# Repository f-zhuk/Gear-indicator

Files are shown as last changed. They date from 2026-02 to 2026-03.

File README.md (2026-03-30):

# Gear-indicator
A system to monitor the selected gear for bicycles, for those who do not trust their memory

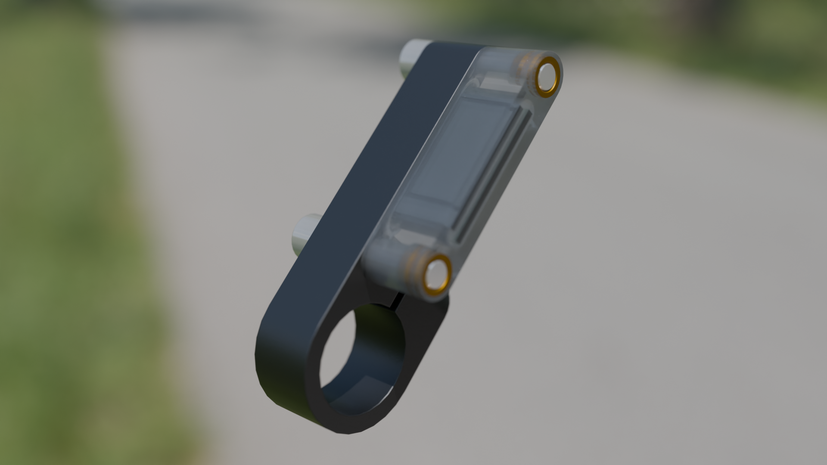
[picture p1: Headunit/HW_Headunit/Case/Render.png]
description


Headunit - a device to display the current gear
Gearunit - a device to transmit the current position of two cables, doubles as a power supply

### System manifest

The main idea of the system is to minimize interaction with the user, reduce buttons and/or settings to the minimum.

The system is designed for long-term/permanent installation and should require minimal maintenance. All its modules should be waterproof and vandal-resistant.

System retains its settings in the local RAM of the corresponding units, always powered from the Battery/shifter unit. If that battery goes flat, all system parameters are lost, and calibration (or learning) should be performed after turning on. Modules can be disconnected from power independently, so it will affect only the related module parameters. 

### Calibration

Whatever position the shifter was left in, it will be considered a first gear after the cold start. First shift has to be upwards, even an incomplete one, to point the cable’s forward direction. If the Headunit reads values outside of the known range, the current gear indicator will move away, and if the value stays stable for ~2 seconds, the gear count and associated shifter value table will be updated.

To save battery, all modules should go in and out of deep sleep upon Headunit's request. While active, deep sleep should be triggered if no movement is detected for a minute. 
While in a deep sleep, any movement should trigger a deep sleep exit.

With an IMU within the battery module firmly attached to the bicycle frame, it is possible to estimate bike speed.

Braking range can be determined and dynamically expanded on the fly.

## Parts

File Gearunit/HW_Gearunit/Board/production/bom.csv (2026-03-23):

Designator | Footprint | Quantity | Value | LCSC Part #
C1, C4, C6, C73 | 0603 | 4 | 1u | CL10A105KB8NNNC
C2, C3, C5, C68, C7 | 0402 | 5 | 100n | CL05B104KB54PNC
D1 | SOT-23 | 1 | SP0502BAHT | SP0502BAHT
F1 | 0603 | 1 | 0603L020YR | 0603L020YR
J1, J2 | XB-PJ-1837 | 2 | XB-PJ-1837 | XB-PJ-1837
J3 | TE_2328702-8_1x08-1MP_P0.5mm_Horizontal | 1 | 2328702-8 | 2328702-8
J4 | HS096T01H13 | 1 | HS096T01H13 | HS096T01H13
Q2, Q3 | SOT-563 | 2 | DMC2400UV | DMC2400UV
R1, R2 | 0805 | 2 | 62R | RC0805FR-0762RL
R10, R13, R3, R4, R5, R6, R8, R9 | 0402 | 8 | 10k | 0402WGF1002TCE
R11, R12, R7 | 0402 | 3 | 10R | 0402WGF100JTCE
U1 | QFN-32-1EP_5x5mm_P0.5mm_EP3.45x3.45mm | 1 | STM32L432KBUx | STM32L432KBU
U2 | SOT-23-3 | 1 | XC6206P332MR-G | XC6206P332MR-G
U3 | DFN-8-1EP_3x3mm_P0.65mm_EP1.5x2.25mm | 1 | SIT1050TK | SIT1050TK

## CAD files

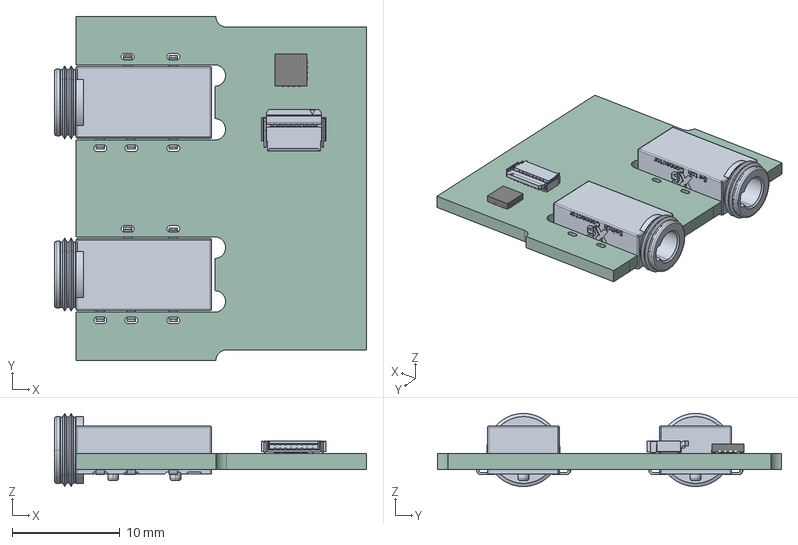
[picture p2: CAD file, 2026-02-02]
Headunit/HW_Headunit/Board/HW_Headunit.step
29.0 x 32.0 x 6.80 mm
c-2328702-8-a-3d
QFN-16-1EP_3x3mm_P0.5mm_EP1.7x1.7mm
xb-pj-1837 x 2
HW_Headunit_PCB

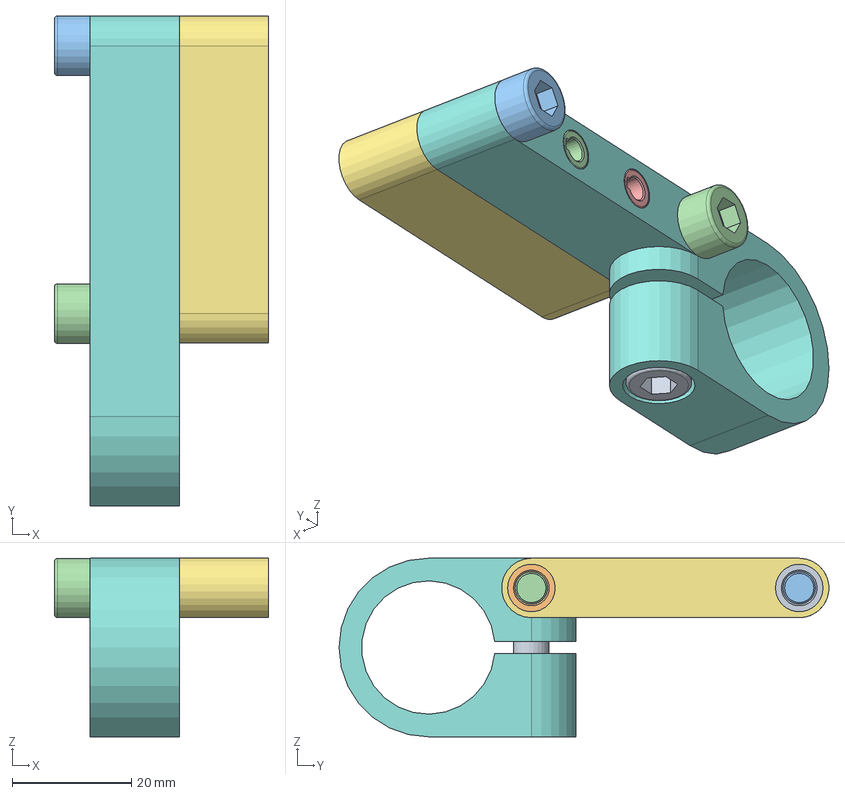
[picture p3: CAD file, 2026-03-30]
Headunit/HW_Headunit/Case/Headunit.FCStd
36.0 x 82.3 x 30.0 mm
DIN912_M6X30_001
DIN912_M6X30_002
R_0402_1005Metric
R_0805_2012Metric
R_0402_1005Metric001
C_0402_1005Metric
R_0402_1005Metric002
SOT-563
R_0402_1005Metric003
R_0402_1005Metric004
SOT-23-3
DFN-8-1EP_3x3mm_P0.65mm_EP1.5x2.25mm
Fuse_0603_1608Metric
C_0603_1608Metric
HS096T01H13
R_0402_1005Metric005
C_0402_1005Metric001
C_0402_1005Metric002
c-2328702-8-a-3d
R_0402_1005Metric006
R_0402_1005Metric007
R_0402_1005Metric008
R_0402_1005Metric009
QFN-32-1EP_5x5mm_P0.5mm_EP3.45x3.45mm
SOT-564
SOT-23
R_0402_1005Metric010
C_0603_1608Metric001
R_0805_2012Metric001
C_0402_1005Metric003
C_0603_1608Metric002
C_0603_1608Metric003
C_0402_1005Metric004
xb-pj-1837
xb-pj-1838
HW_Headunit_PCB
DIN912_M6X12_001

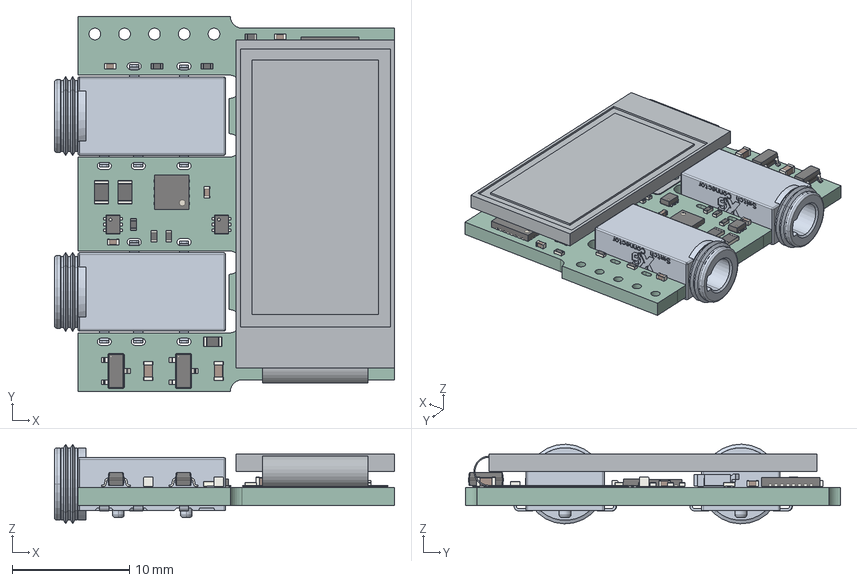
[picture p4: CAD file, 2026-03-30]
Headunit/HW_Headunit/Case/HW_Headunit.step
29.0 x 32.0 x 6.80 mm
R_0402_1005Metric x 11
R_0805_2012Metric x 2
C_0402_1005Metric x 5
SOT-563 x 2
SOT-23-3
DFN-8-1EP_3x3mm_P0.65mm_EP1.5x2.25mm
Fuse_0603_1608Metric
C_0603_1608Metric x 4
HS096T01H13
c-2328702-8-a-3d
QFN-32-1EP_5x5mm_P0.5mm_EP3.45x3.45mm
SOT-23
xb-pj-1837 x 2
HW_Headunit_PCB

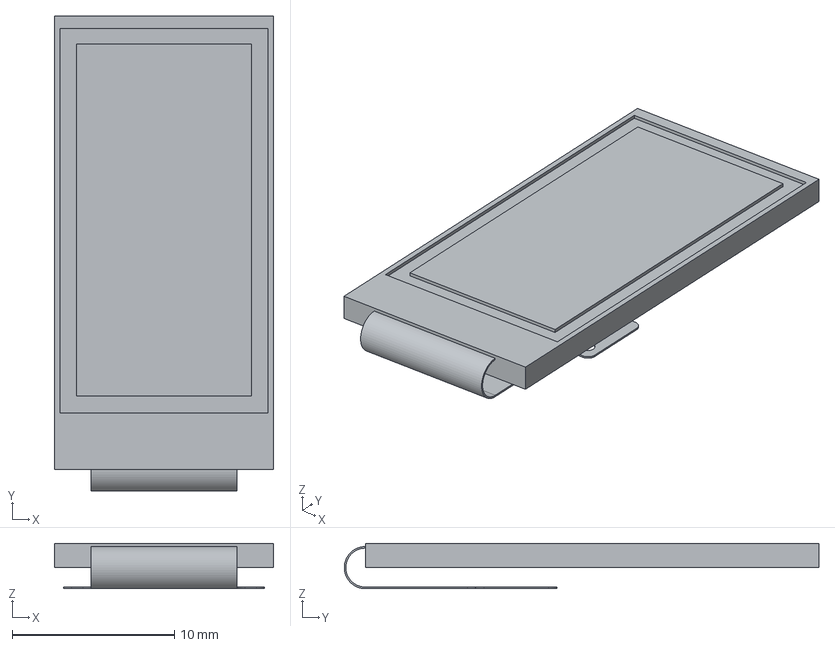
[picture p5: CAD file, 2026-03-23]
Headunit/HW_Headunit/Case/HS096T01H13.step
13.5 x 29.2 x 2.80 mm

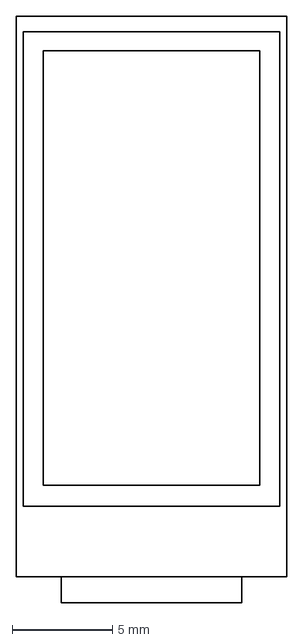
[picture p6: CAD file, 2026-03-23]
Headunit/HW_Headunit/Case/HS096T01H13-Shape2DView.dxf
13.5 x 29.2 mm

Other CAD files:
Headunit/HW_Headunit/Case/LH096NT-IF09W.step
Headunit/HW_Headunit/Case/HS096T01H13.FCStd
Headunit/HW_Headunit/Case/Headunit.blend
Headunit/HW_Headunit/Case/LH096NT-IF09W.FCStd

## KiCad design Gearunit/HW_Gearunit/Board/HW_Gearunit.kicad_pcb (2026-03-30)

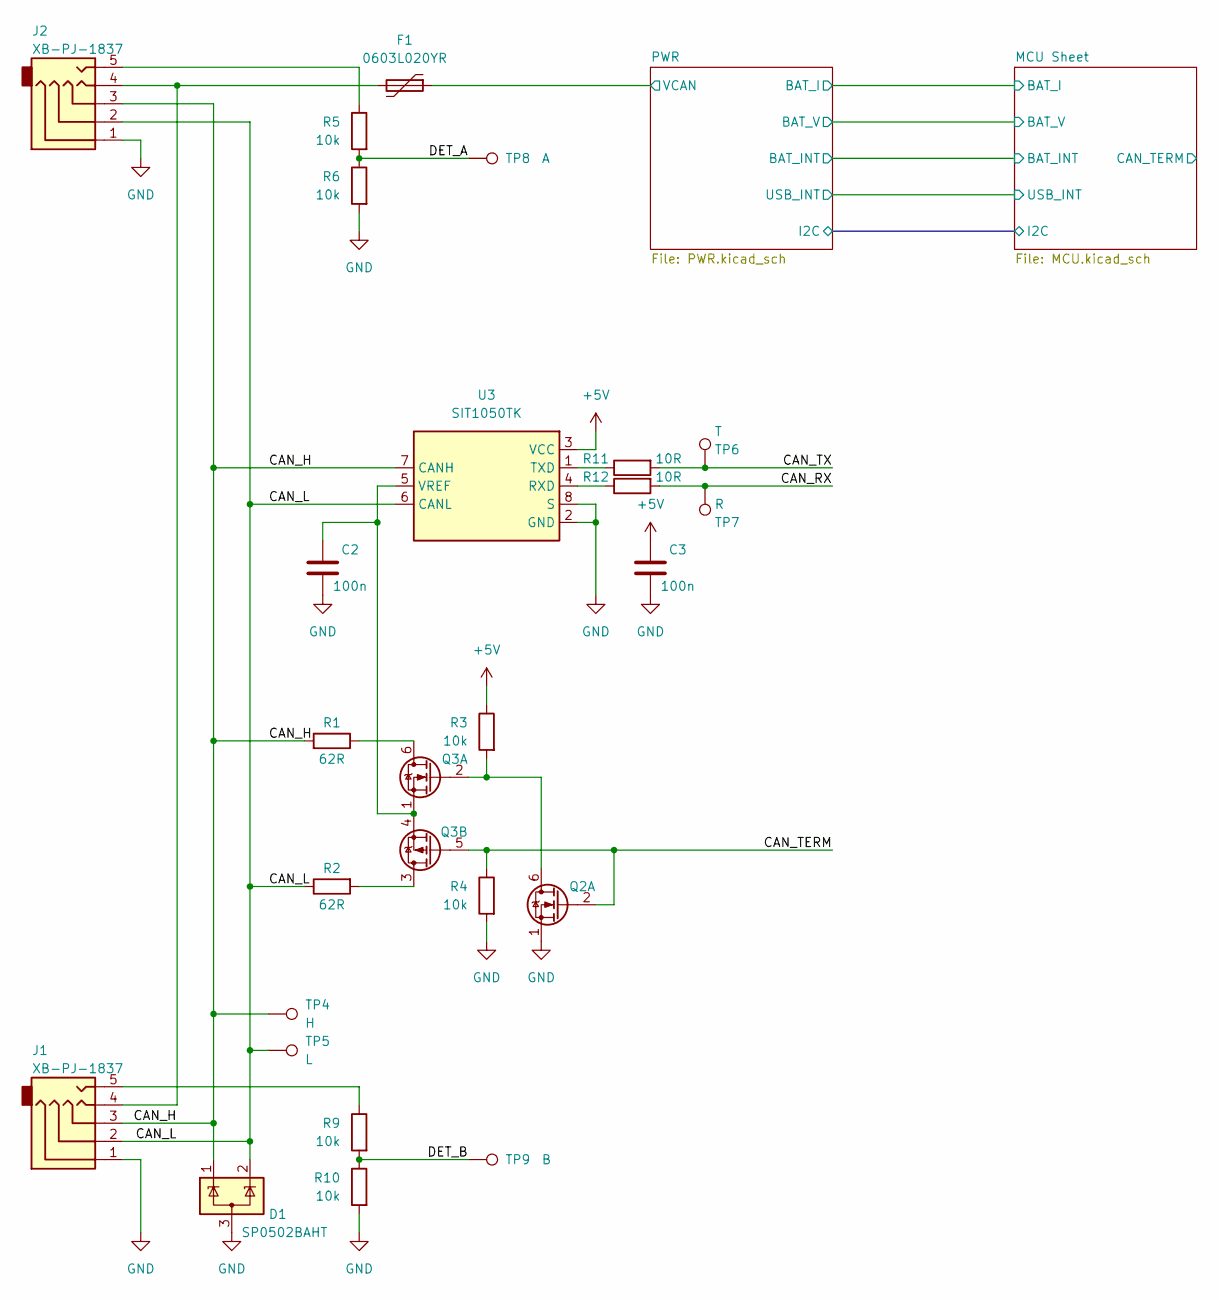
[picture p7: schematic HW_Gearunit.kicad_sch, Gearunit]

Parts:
C2, C3: 100n; C_0402_1005Metric; MPN CL05B104KB54PNC
D1: SP0502BAHT; SOT-23; MPN SP0502BAHT
F1: 0603L020YR; Fuse_0603_1608Metric; MPN 0603L020YR
J1, J2: XB-PJ-1837; MPN XB-PJ-1837
Q2, Q3: DMC2400UV; SOT-563; MPN DMC2400UV
R1, R2: 62R; R_0805_2012Metric; MPN RC0805FR-0762RL
R3, R4, R5, R6, R9, R10: 10k; R_0402_1005Metric; MPN 0402WGF1002TCE
R11, R12: 10R; R_0402_1005Metric; MPN 0402WGF100JTCE
TP4: H; TestPoint_Pad_D1.5mm
TP5: L; TestPoint_Pad_D1.5mm
TP6: T; TestPoint_Pad_D1.5mm
TP7: R; TestPoint_Pad_D1.5mm
TP8: A; TestPoint_Pad_D1.5mm
TP9: B; TestPoint_Pad_D1.5mm
U3: SIT1050TK; DFN-8-1EP_3x3mm_P0.65mm_EP1.5x2.25mm; MPN SIT1050TK

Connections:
+5V: C3.2, R3.1, U3.3 (VCC)
/CAN_H: D1.1 (K), J1.3, J2.3, R1.2, TP4.1, U3.7 (CANH)
/CAN_L: D1.2 (K), J1.2, J2.2, R2.1, TP5.1, U3.6 (CANL)
/CAN_RX: R12.2, TP7.1
/CAN_TERM: Q2.2 (G), Q3.5 (G), R4.1
/CAN_TX: R11.2, TP6.1
/DET_A: R5.2, R6.1, TP8.1
/DET_B: R9.2, R10.1, TP9.1
/PWR/VCAN: F1.1; also elsewhere on the board
GND: C2.1, C3.1, D1.3 (A), J1.1, J2.1, Q2.1 (S), R4.2, R6.2, R10.2, U3.2 (GND), U3.8 (S); also elsewhere on the board
unnamed: F1.2, J1.4, J2.4
unnamed: J1.5, R9.1
unnamed: J2.5, R5.1
unnamed: Q2.6 (D), Q3.2 (G), R3.2
unnamed: Q3.6 (D), R1.1
unnamed: C2.2, Q3.1 (S), Q3.4 (S), U3.5 (VREF)
unnamed: Q3.3 (D), R2.2
unnamed: R12.1, U3.4 (RXD)
unnamed: R11.1, U3.1 (TXD)

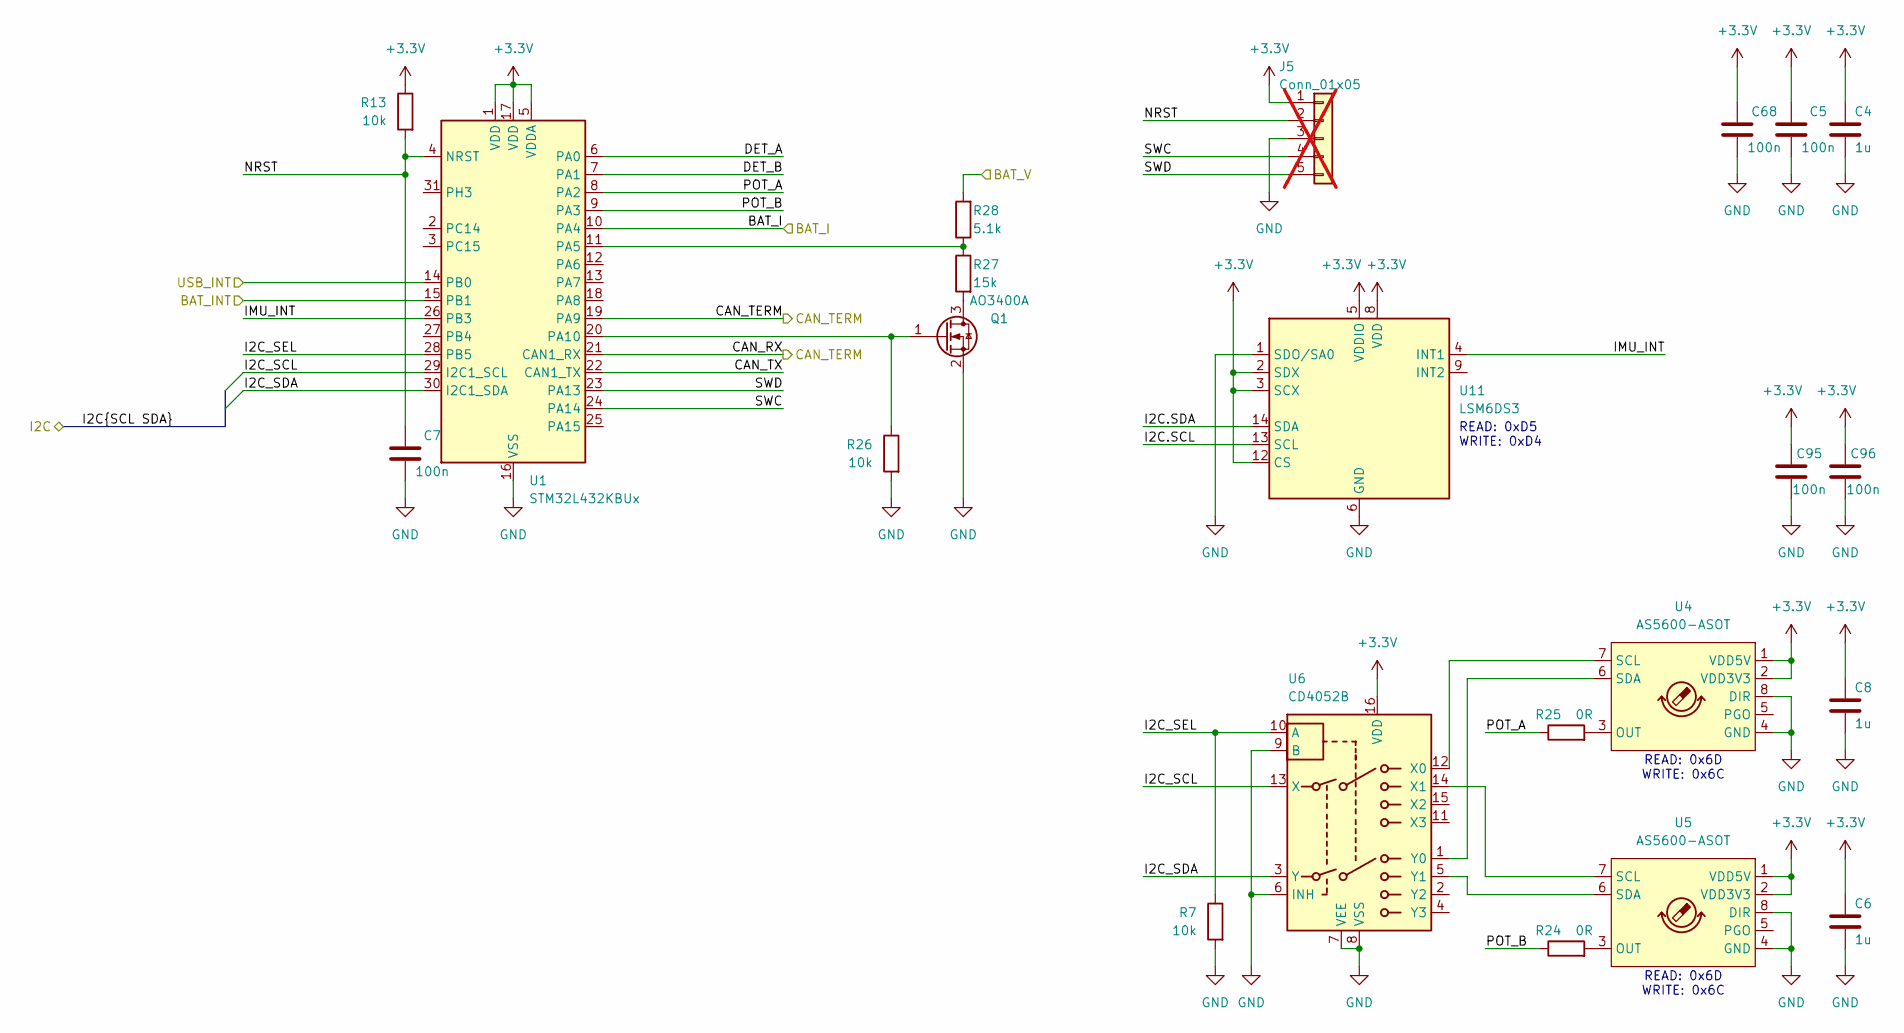
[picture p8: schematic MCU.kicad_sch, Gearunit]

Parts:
C4, C6, C8: 1u; C_0603_1608Metric; MPN CL10A105KB8NNNC
C5, C7, C68, C95, C96: 100n; C_0402_1005Metric; MPN CL05B104KB54PNC
J5: Conn_01x05; PinHeader_1x05_P2.54mm_Vertical; not fitted
Q1: AO3400A; SOT-23; MPN AO3400A
R7, R13, R26: 10k; R_0402_1005Metric; MPN 0402WGF1002TCE
R24, R25: 0R; R_0402_1005Metric; MPN 0402WGF0000TCE
R27: 15k; R_0402_1005Metric; MPN 0402WGF1502TCE
R28: 5.1k; R_0402_1005Metric; MPN 0402WGF5101TCE
U1: STM32L432KBUx; QFN-32-1EP_5x5mm_P0.5mm_EP3.45x3.45mm; MPN STM32L432KBU
U4, U5: AS5600-ASOT; SO-8_3.9x4.9mm_P1.27mm; MPN AS5600-ASOT
U6: CD4052B; TSSOP-16_4.4x5mm_P0.65mm
U11: LSM6DS3; LGA-14_3x2.5mm_P0.5mm_LayoutBorder3x4y; MPN LSM6DS3

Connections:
+3.3V: C4.2, C5.2, C6.2, C8.2, C68.2, C95.1, C96.1, J5.1, R13.1, U1.1 (VDD), U1.5 (VDDA), U1.17 (VDD), U4.1 (VDD5V), U4.2 (VDD3V3), U5.1 (VDD5V), U5.2 (VDD3V3), U6.16 (VDD), U11.2 (SDX), U11.3 (SCX), U11.5 (VDDIO), U11.8 (VDD), U11.12 (CS); also elsewhere on the board
/MCU Sheet/BAT_I: U1.10 (PA4); also elsewhere on the board
/MCU Sheet/BAT_INT: U1.15 (PB1); also elsewhere on the board
/MCU Sheet/BAT_V: R28.2; also elsewhere on the board
/MCU Sheet/CAN_RX: U1.19 (PA9), U1.21 (CAN1_RX)
/MCU Sheet/CAN_TX: U1.22 (CAN1_TX)
/MCU Sheet/DET_A: U1.6 (PA0)
/MCU Sheet/DET_B: U1.7 (PA1)
/MCU Sheet/I2C.SCL: U11.13 (SCL); also elsewhere on the board
/MCU Sheet/I2C.SDA: U11.14 (SDA); also elsewhere on the board
/MCU Sheet/I2C_SCL: U1.29 (I2C1_SCL), U6.13 (X)
/MCU Sheet/I2C_SDA: U1.30 (I2C1_SDA), U6.3 (Y)
/MCU Sheet/I2C_SEL: R7.1, U1.28 (PB5), U6.10 (A)
/MCU Sheet/IMU_INT: U1.26 (PB3), U11.4 (INT1)
/MCU Sheet/NRST: C7.2, J5.2, R13.2, U1.4 (NRST)
/MCU Sheet/POT_A: R25.1, U1.8 (PA2)
/MCU Sheet/POT_B: R24.1, U1.9 (PA3)
/MCU Sheet/SWC: J5.4, U1.24 (PA14)
/MCU Sheet/SWD: J5.5, U1.23 (PA13)
/MCU Sheet/USB_INT: U1.14 (PB0); also elsewhere on the board
GND: C4.1, C5.1, C6.1, C7.1, C8.1, C68.1, C95.2, C96.2, J5.3, Q1.2 (S), R7.2, R26.2, U1.16 (VSS), U1.32 (VSS), U1.33 (VSS), U4.4 (GND), U4.8 (DIR), U5.4 (GND), U5.8 (DIR), U6.6 (INH), U6.7 (VEE), U6.8 (VSS), U6.9 (B), U11.1 (SDO/SA0), U11.6 (GND), U11.7 (GND); also elsewhere on the board
unnamed: Q1.3 (D), R27.2
unnamed: Q1.1 (G), R26.1, U1.20 (PA10)
unnamed: R27.1, R28.1, U1.11 (PA5)
unnamed: R25.2, U4.3 (OUT)
unnamed: U4.7 (SCL), U6.12 (X0)
unnamed: U4.6 (SDA), U6.1 (Y0)
unnamed: R24.2, U5.3 (OUT)
unnamed: U5.7 (SCL), U6.14 (X1)
unnamed: U5.6 (SDA), U6.5 (Y1)

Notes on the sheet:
READ: 0x6D WRITE: 0x6C
READ: 0xD5 WRITE: 0xD4

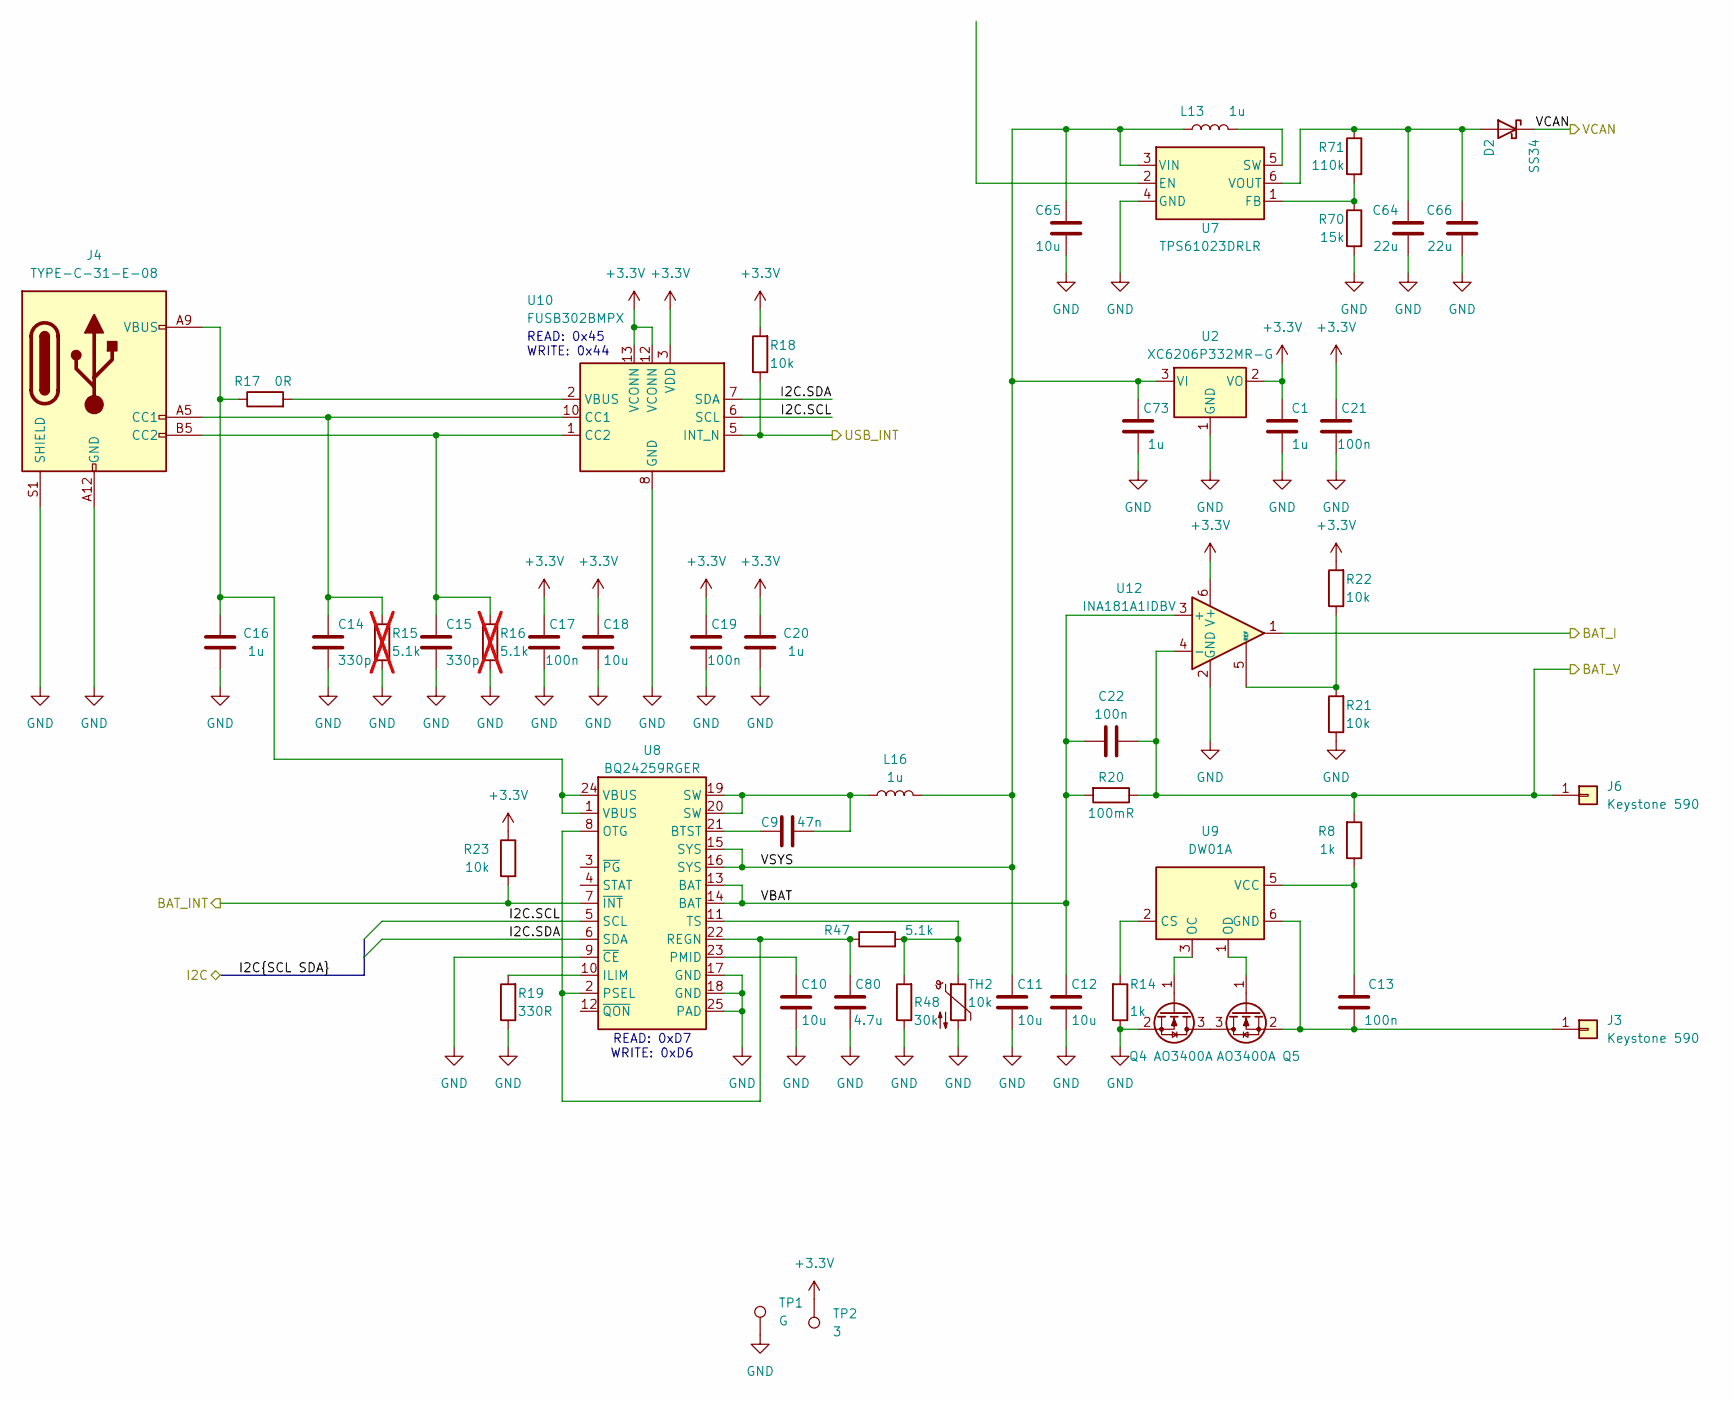
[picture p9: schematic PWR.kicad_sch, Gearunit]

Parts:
C1, C16, C20, C73: 1u; C_0603_1608Metric; MPN CL10A105KB8NNNC
C9: 47n; C_0402_1005Metric; MPN GRM155R71E473KA88D
C10, C11, C12, C18, C65: 10u; C_0603_1608Metric; MPN CL10A106MA8NRNC
C13, C17, C19, C21, C22: 100n; C_0402_1005Metric; MPN CL05B104KB54PNC
C14, C15: 330p; C_0402_1005Metric; MPN CL05C331JB5NNNC
C64, C66: 22u; C_0805_2012Metric; MPN CL21A226MAQNNNE
C80: 4.7u; C_0603_1608Metric; MPN CL10A475KO8NNNC
D2: SS34; D_SMA; MPN SS34
J3, J6: Keystone 590; Connector_Keystone_590; MPN 590
J4: TYPE-C-31-E-08; USB_C_Receptacle_HRO_TYPE-C-31-E-08; MPN TYPE-C-31-E-08
L13, L16: 1u; L_Murata_DFE201610P; MPN DFE201610E-1R0M=P2
Q4, Q5: AO3400A; SOT-23; MPN AO3400A
R8, R14: 1k; R_0402_1005Metric; MPN 0402WGF1001TCE
R15, R16: 5.1k; R_0402_1005Metric; MPN 0402WGF5101TCE; not fitted
R17: 0R; R_0402_1005Metric; MPN 0402WGF0000TCE
R18, R21, R22, R23: 10k; R_0402_1005Metric; MPN 0402WGF1002TCE
R19: 330R; R_0402_1005Metric; MPN 0402WGF3300TCE
R20: 100mR; R_0603_1608Metric; MPN ERJ3RSFR10V
R47: 5.1k; R_0402_1005Metric; MPN 0402WGF5101TCE
R48: 30k; R_0603_1608Metric; MPN 0603WAF3002T5E
R70: 15k; R_0402_1005Metric; MPN 0402WGF1502TCE
R71: 110k; R_0603_1608Metric; MPN 0603WAF1103T5E
TH2: 10k; R_0603_1608Metric; MPN SDNT1608X103F3435FTF
TP1: G; TestPoint_Pad_D1.5mm
TP2: 3; TestPoint_Pad_D1.5mm
U2: XC6206P332MR-G; SOT-23-3; MPN XC6206P332MR-G
U7: TPS61023DRLR; SOT-563; MPN TPS61023DRLR
U8: BQ24259RGER; Texas_RGE0024H_VQFN-24-1EP_4x4mm_P0.5mm_EP2.7x2.7mm
U9: DW01A; SOT-23-6
U10: FUSB302BMPX; WQFN-14-1EP_2.5x2.5mm_P0.5mm_EP1.45x1.45mm; MPN FUSB302BMPX
U12: INA181A1IDBV; SOT-23-6; MPN INA181A1IDBV

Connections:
+3.3V: C1.2, C17.1, C18.2, C19.1, C20.2, C21.1, R18.2, R22.2, R23.1, TP2.1, U2.2 (VO), U10.3 (VDD), U10.4 (VDD), U10.12 (VCONN), U10.13 (VCONN), U12.6 (V+); also elsewhere on the board
/MCU Sheet/BAT_I: U12.1; also elsewhere on the board
/MCU Sheet/BAT_INT: R23.2, U8.7 (~INT); also elsewhere on the board
/MCU Sheet/BAT_V: C22.2, J6.1, R8.2, R20.1, U12.4 (-); also elsewhere on the board
/MCU Sheet/I2C.SCL: U8.5 (SCL), U10.6 (SCL); also elsewhere on the board
/MCU Sheet/I2C.SDA: U8.6 (SDA), U10.7 (SDA); also elsewhere on the board
/MCU Sheet/USB_INT: R18.1, U10.5 (INT_N); also elsewhere on the board
/PWR/VBAT: C12.2, C22.1, R20.2, U8.13 (BAT), U8.14 (BAT), U12.3 (+)
/PWR/VCAN: D2.1 (K); also elsewhere on the board
/PWR/VSYS: C11.2, C65.2, C73.2, L13.2, L16.2, U2.3 (VI), U7.3 (VIN), U8.15 (SYS), U8.16 (SYS)
GND: C1.1, C10.1, C11.1, C12.1, C14.1, C15.1, C16.1, C17.2, C18.1, C19.2, C20.1, C21.2, C64.2, C65.1, C66.2, C73.1, C80.1, J4.A12 (GND), J4.B12 (GND), J4.S1 (SHIELD), Q4.2 (S), R14.1, R15.2, R16.2, R19.1, R21.1, R48.1, R70.2, TH2.2, TP1.1, U2.1 (GND), U7.4 (GND), U8.9 (~CE), U8.17 (GND), U8.18 (GND), U8.25 (PAD), U10.8 (GND), U10.9 (GND), U10.15 (GND), U12.2 (GND); also elsewhere on the board
unnamed: C9.2, L16.1, U8.19 (SW), U8.20 (SW)
unnamed: C16.2, J4.A9 (VBUS), J4.B9 (VBUS), R17.1, U8.1 (VBUS), U8.24 (VBUS)
unnamed: C64.1, C66.1, D2.2 (A), R71.1, U7.6 (VOUT)
unnamed: C13.1, J3.1, Q5.2 (S), U9.6 (GND)
unnamed: C14.2, J4.A5 (CC1), R15.1, U10.10 (CC1), U10.11 (CC1)
unnamed: C15.2, J4.B5 (CC2), R16.1, U10.1 (CC2), U10.14 (CC2)
unnamed: Q4.3 (D), Q5.3 (D)
unnamed: Q4.1 (G), U9.3 (OC)
unnamed: Q5.1 (G), U9.1 (OD)
unnamed: R70.1, R71.2, U7.1 (FB)
unnamed: L13.1, U7.5 (SW)
unnamed: C9.1, U8.21 (BTST)
unnamed: R19.2, U8.10 (ILIM)
unnamed: C80.2, R47.1, U8.2 (PSEL), U8.8 (OTG), U8.22 (REGN)
unnamed: C10.2, U8.23 (PMID)
unnamed: R47.2, R48.2, TH2.1, U8.11 (TS)
unnamed: R14.2, U9.2 (CS)
unnamed: C13.2, R8.1, U9.5 (VCC)
unnamed: R17.2, U10.2 (VBUS)
unnamed: R21.2, R22.1, U12.5 (REF)

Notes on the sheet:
READ: 0x45 WRITE: 0x44
READ: 0xD7 WRITE: 0xD6

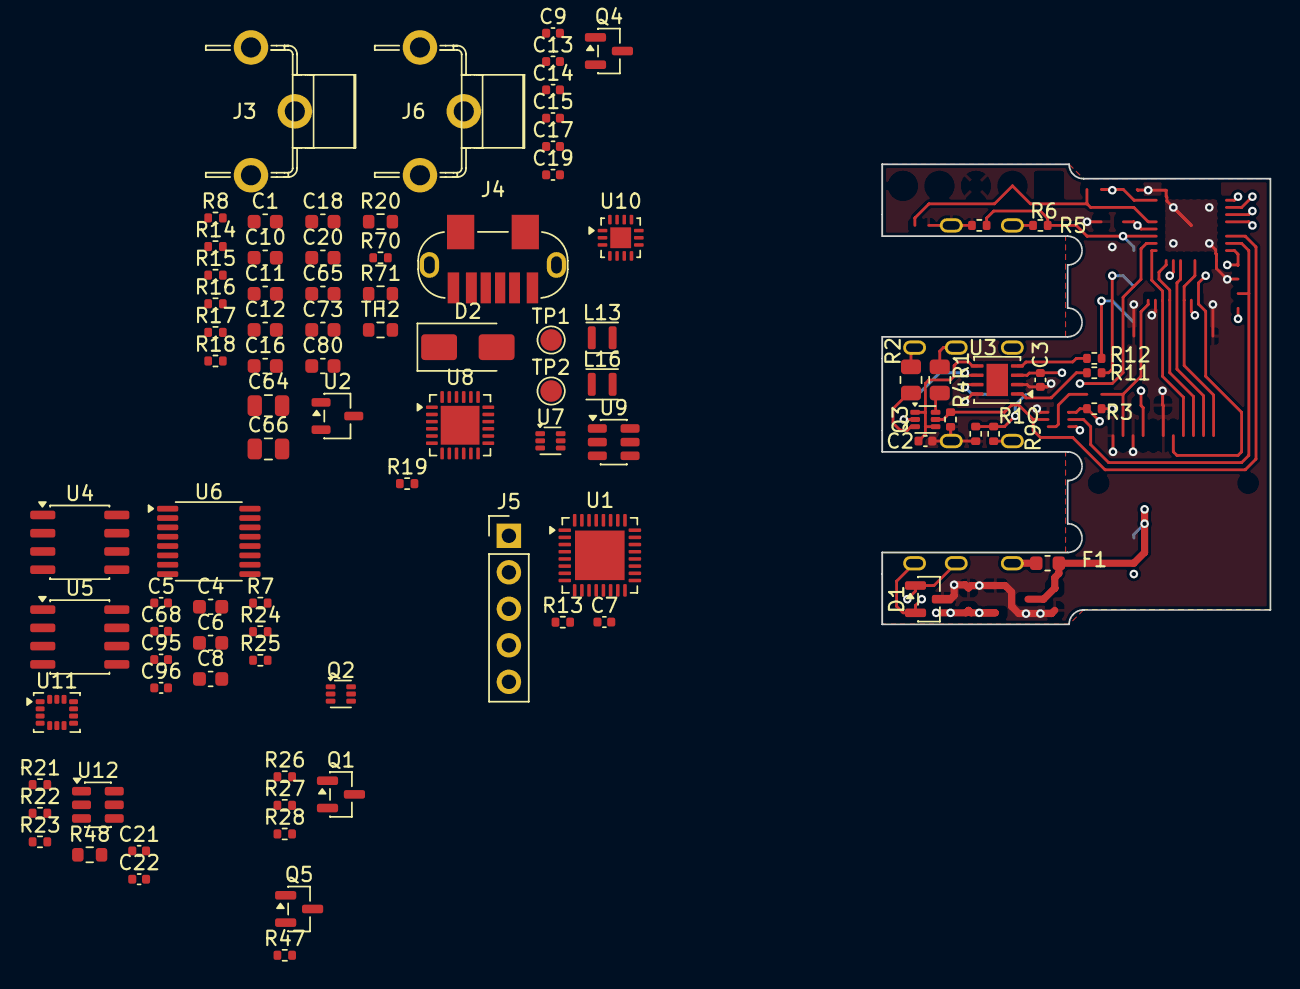
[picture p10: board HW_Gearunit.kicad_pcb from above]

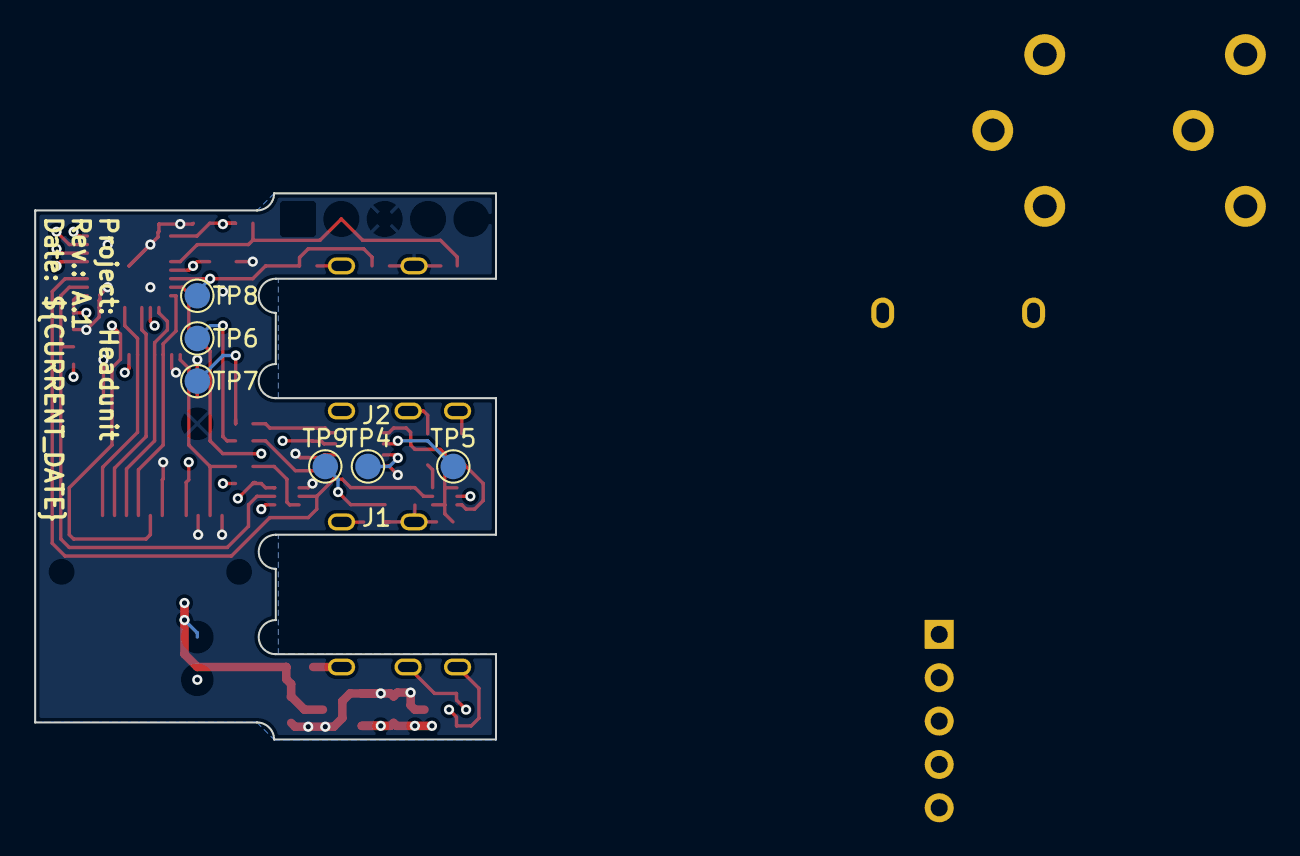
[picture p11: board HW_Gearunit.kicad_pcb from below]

Board: 4 copper layers, 27.0 x 32.0 mm, 99 parts (8 on the bottom side), 67 nets.

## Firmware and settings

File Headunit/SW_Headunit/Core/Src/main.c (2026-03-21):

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
/* Includes ------------------------------------------------------------------*/
#include "main.h"

/* USER CODE BEGIN Includes */
#include "CO_app_STM32.h"
#include "OD.h"
#include "ST7735.h"
#include "display.h"
#include "fonts.h"
/* USER CODE END Includes */

/* USER CODE BEGIN PTD */
enum DIRECTION_ENUM // арифметическая операция
{
  DIRECTION_DOWN = -1,
  DIRECTION_UNKNOWN,
  DIRECTION_UP
};

typedef struct {
  OD_entry_t* CAN_entry;
  int8_t direction;
  //uint8_t gear;
  uint8_t gear_total;
  uint8_t position[16];
  uint8_t log[32];
} shifter_descriptor;
/* USER CODE END PTD */

CAN_HandleTypeDef hcan;

SPI_HandleTypeDef hspi1;

TIM_HandleTypeDef htim4;

/* USER CODE BEGIN PV */
shifter_descriptor shifter[2];
/* USER CODE END PV */

void SystemClock_Config(void);
static void MX_GPIO_Init(void);
static void MX_CAN_Init(void);
static void MX_SPI1_Init(void);
static void MX_TIM4_Init(void);
/* USER CODE BEGIN 0 */
/* Timer interrupt function executes every 1 ms */
void HAL_TIM_PeriodElapsedCallback(TIM_HandleTypeDef* htim) 
{
  static uint16_t overflow_counter = 0; //15:12 - reserved, 11:7 - 32 samples, 6 - shifter interleave, 5:1 64ms delay
  int16_t shift = 0; //Needed for easier operations with boudaries
  uint8_t sh_num;
  if (htim == canopenNodeSTM32->timerHandle) 
  {
    canopen_app_interrupt();
  }
  //HAL_GPIO_TogglePin(GPIOC, GPIO_PIN_13);
  overflow_counter ++;
  if ((overflow_counter&0x3F) == 0x3F) // Triggered every 64 ms
  {
    sh_num = (overflow_counter>>6)&1;
    OD_get_u8(shifter[sh_num].CAN_entry, 0x01+sh_num, (uint8_t*)&shift, false); //get shifter value

    if (shift==0) // Reserved default value meaning absence of real data
      return;
    else if (shifter[sh_num].gear_total == 0) // Triggered only at startup to get initial valid position
    {
      //shifter[sh_num].gear = 1;
      shifter[sh_num].gear_total = 1;
      shifter[sh_num].position[1] = shift;
    }

    if((shifter[sh_num].gear_total != 0) && (shifter[sh_num].direction == DIRECTION_UNKNOWN)) // Only for first shift detection
    {
      if (shift-5 >= (shifter[sh_num].position[ 1 ]))
        shifter[sh_num].direction = DIRECTION_UP;
      else if (shift+5 < (shifter[sh_num].position[ 1 ]))
        shifter[sh_num].direction = DIRECTION_DOWN;
    }
      
    shifter[sh_num].log[(overflow_counter>>7)&0x0F] = shift; // Storing 16*128ms of samples

      if (((overflow_counter>>7)&0x0F) == 0x0F) // When we got all 16 samples
      {
        int16_t min = 255;
        int16_t max = 0;
        for(uint8_t i = 0; i<16; i++) //searching for lowest and highhest values
        {
          if (shifter[sh_num].log[i] < min)
            min = shifter[sh_num].log[i];
          if (shifter[sh_num].log[i] > max)
            max = shifter[sh_num].log[i];
        }

        if ((max-min)>5) // discard all if movement not finished or deviation is too high
          return;

        if (shifter[sh_num].gear_total >= 15) // discard all if max gear count per shipter reached
          return;

        if (shifter[sh_num].direction == DIRECTION_UNKNOWN) // discard all if no direction was defined yet
          return;

        if (shifter[sh_num].direction == DIRECTION_UP)
        {
          if ((min-5) >= shifter[sh_num].position[ shifter[sh_num].gear_total ])
          {
            //shifter[sh_num].gear = gear_total;
            shifter[sh_num].gear_total += 1;
            shifter[sh_num].position[shifter[sh_num].gear_total] = (max+min)/2;
          }
          else if ((max+5) <= (shifter[sh_num].position[ 1 ]))
          {
            //shifter[sh_num].gear =1;
            shifter[sh_num].gear_total += 1;
            for(uint8_t i = shifter[sh_num].gear_total; i>1; i--) // moving all positions up to add one gear to the bottom 
            {
              shifter[sh_num].position[i] = shifter[sh_num].position[i-1];
            }
            shifter[sh_num].position[ 1 ] = (max+min)/2;
          }
        }

        if (shifter[sh_num].direction == DIRECTION_DOWN)
        {
          if ((min-5) >= shifter[sh_num].position[ 1 ])
          {
            //shifter[sh_num].gear = gear_total;
            shifter[sh_num].gear_total += 1;
            for(uint8_t i = shifter[sh_num].gear_total; i>1; i--) // moving all positions up to add one gear to the bottom 
            {
              shifter[sh_num].position[i] = shifter[sh_num].position[i-1];
            }
            shifter[sh_num].position[ 1 ] = (max+min)/2;
          }
          else if ((max+5) <= (shifter[sh_num].position[ shifter[sh_num].gear_total ]))
          {
            //shifter[sh_num].gear =1;
            shifter[sh_num].gear_total += 1;
            shifter[sh_num].position[shifter[sh_num].gear_total] = (max+min)/2;
          }
        }
      }
  }
}
/* USER CODE END 0 */

/**
  * @brief  The application entry point.
  * @retval int
  */
int main(void)
{

  /* MCU Configuration--------------------------------------------------------*/

  /* Reset of all peripherals, Initializes the Flash interface and the Systick. */
  HAL_Init();

  /* Configure the system clock */
  SystemClock_Config();

  /* USER CODE BEGIN SysInit */
  for(uint8_t i = 0; i<2; i++)
  {
    shifter[i].CAN_entry = OD_find(OD,0x6001); //Same Index, different subindices
    shifter[i].direction = DIRECTION_UNKNOWN;
    shifter[i].gear_total = 0;
    for(uint8_t j = 0; j<16; j++)
    {
      shifter[i].position[j]=0;
    }
    for(uint8_t j = 0; j<32; j++)
    {
      shifter[i].log[j]=0;
    }
  }
  /* USER CODE END SysInit */

  /* Initialize all configured peripherals */
  MX_GPIO_Init();
  MX_CAN_Init();
  MX_SPI1_Init();
  MX_TIM4_Init();
  /* USER CODE BEGIN 2 */

  CANopenNodeSTM32 canOpenNodeSTM32;
  canOpenNodeSTM32.CANHandle = &hcan;
  canOpenNodeSTM32.HWInitFunction = MX_CAN_Init;
  canOpenNodeSTM32.timerHandle = &htim4;
  canOpenNodeSTM32.desiredNodeID = 3;
  canOpenNodeSTM32.baudrate = 125;
  canopen_app_init(&canOpenNodeSTM32);

  initR(&hspi1);
  displayInit(getBufferPointer(), ST7735_WIDTH, ST7735_HEIGHT);
  enableDisplay(false);
  enableInvert(true);
  setCursor(0,0);
  fillRectangle(80,160,0x00);

  redraw();
  enableDisplay(true);
  /* USER CODE END 2 */

  /* Infinite loop */
  /* USER CODE BEGIN WHILE */
  uint8_t i=0;
  uint8_t trigger=0;
  uint8_t shift[2]={0, 0};
  //CO_NMT_t state;

  setCursor(2,2);
  while (1)
  {
    canopen_app_process();

    setCursor(0,0);
    fillRectangle(80,60,0x00);
    OD_get_u8(OD_find(OD,0x6001), 0x01, &shift[0], false);

    if ((shift[0]==0) || (shifter[0].gear_total==0) || (shifter[0].direction==DIRECTION_UNKNOWN))
    {
      setCursor(30,40);
      putChar('?', lv_font_montserrat_40, 0);
    }
    else 
    {
      uint8_t gear = 1;
      while ((shifter[0].direction*shift[0] > shifter[0].direction*shifter[0].position[gear]) && (gear<=shifter[0].gear_total)) 
          gear++;
      /*if (shifter[0].direction==DIRECTION_UP)
      {
        while ((shift[0] > shifter[0].position[gear]) && (gear<=shifter[0].gear_total)) 
          gear++;
      }
      else if (shifter[0].direction==DIRECTION_DOWN)
      {
        while ((shift[0] > shifter[0].position[gear]) && (gear<=shifter[0].gear_total)) 
          gear++;
      }*/

      if(gear == 1) //possible only below the range
      {
        setCursor(30,40+shifter[0].direction*(shifter[0].position[gear] - shift[0]));
        putChar('1'/*+gear-1*/, lv_font_montserrat_40, 0);
      }
      else if (gear > shifter[0].gear_total) //possible only above the range
      {
        gear--;
        setCursor(30,40+shifter[0].direction*(shifter[0].position[gear] - shift[0]));
        putChar('1'+gear-1, lv_font_montserrat_40, 0);
      }
      else
      {
        uint8_t offset = 56*((int16_t)shift[0] - (int16_t)shifter[0].position[gear-1])/((int16_t)shifter[0].position[gear]-(int16_t)shifter[0].position[gear-1]);
        setCursor(30,40-offset);
        putChar('1'+gear-2, lv_font_montserrat_40, 0);
        setCursor(30,40+20+36-offset);
        putChar('1'+gear-1, lv_font_montserrat_40, 0);
      }

    }

    /*setCursor(0,60);
    fillRectangle(80,60,0x00);
    setCursor(0,70);
    putNumber_u8(shift[0], lv_font_unscii_8, RGBI_LT_GREEN);
    setCursor(0,80);
    putNumber_u8(shifter[0].gear_total, lv_font_unscii_8, RGBI_LT_GREEN);
    setCursor(0,90);
    if(shifter[0].direction==DIRECTION_UNKNOWN)
      putChar('?', lv_font_unscii_8, RGBI_WHITE);
    else if(shifter[0].direction==DIRECTION_UP)
      putChar('U', lv_font_unscii_8, RGBI_WHITE);
    else if(shifter[0].direction==DIRECTION_DOWN)
      putChar('D', lv_font_unscii_8, RGBI_WHITE);

    for(uint8_t j=0; j<shifter[0].gear_total; j++)
    {
      setCursor(0,100+j*10);
      putNumber_u8(shifter[0].position[j+1], lv_font_unscii_8, RGBI_LT_GREEN);
    }


    setCursor(-shift,36);
    putChar('1', lv_font_montserrat_40, 0);
    putChar('2', lv_font_montserrat_40, 0);
    putChar('1', lv_font_montserrat_20, 0);
    putChar('2', lv_font_montserrat_20, 0);
    setCursor(-shift,60);
    putString("CHECK: ", lv_font_unscii_8, RGBI_LT_GREEN);
    setCursor(-shift,70);
    putString("WARNING: ", lv_font_unscii_8, 14);
    setCursor(-shift,80);
    putString("ERROR: ", lv_font_unscii_8, 12);
    setCursor(70,80);
    putChar('8', lv_font_unscii_8, 0xF);
    putChar('1', lv_font_unscii_8, 0x1);
    putChar('2', lv_font_unscii_8, 0x3);
    putChar('3', lv_font_unscii_8, 0x5);
    putChar('4', lv_font_unscii_8, 0x7);
    putChar('5', lv_font_unscii_8, 0x9);
    putChar('6', lv_font_unscii_8, 0xB);
    putChar('7', lv_font_unscii_8, 0xD);
    putChar('8', lv_font_unscii_8, 0xF);*/
    
    //setCursor(0,55);
    //fillRectangle(80,25,0x00);
    //setCursor(10,70);
    //putChar(0x30+shifter[0].gear_total);
    //setCursor(30,70);
    //putChar(0x30+shifter[1].gear_total);
    
    //setCursor(0,0);
    //fillRectangle(80,10,i);
    //setCursor(0,10);
    //fillRectangle(80,10,0x01);
    //setCursor(0,20);
    //fillRectangle(80,10,0x02);
    //setCursor(0,30);
    //fillRectangle(80,10,0x03);
    
/*
    setCursor(0,40);
    fillRectangle(80,10,0x04);
    setCursor(0,50);
    fillRectangle(80,10,0x05);
    setCursor(0,60);
    fillRectangle(80,10,0x06);
    setCursor(0,70);
    fillRectangle(80,10,0x07);
    setCursor(0,80);
    fillRectangle(80,10,0x08);
    setCursor(0,90);
    fillRectangle(80,10,0x09);
    setCursor(0,100);
    fillRectangle(80,10,0x0A);
    setCursor(0,110);
    fillRectangle(80,10,0x0B);
    setCursor(0,120);
    fillRectangle(80,10,0x0C);
    setCursor(0,130);
    fillRectangle(80,10,0x0D);
    setCursor(0,140);
    fillRectangle(80,10,0x0E);
    setCursor(0,150);
    fillRectangle(80,10,0x0F);s*/

    //fillRectangle(20,2,i);
    i++;
    
    if (!redraw_busy)
    {
      //if (trigger)
        redraw_partial(0, 0, ST7735_WIDTH, 50, (uint16_t*)&st7735_palette);
      //else
      //  redraw_partial(0, 50, ST7735_WIDTH, 110, (uint16_t*)&st7735_palette_rgbi);
      trigger ^= 0x01;
    }
      //redraw_partial(0, 0, ST7735_WIDTH, 44, (uint16_t*)&st7735_palette);
      //redraw_partial(0, i&0x1F, ST7735_WIDTH, 80, (uint16_t*)&st7735_palette_rgbi);
    //redraw_partial(0, 80, ST7735_WIDTH, 160, (uint16_t*)&st7735_palette);
    //redraw_partial(0, 0, ST7735_WIDTH, 80, (uint16_t*)&st7735_palette_red);

    HAL_Delay(10);
    HAL_GPIO_TogglePin(GPIOC, GPIO_PIN_13);
    /* USER CODE END WHILE */

    /* USER CODE BEGIN 3 */
  }
  /* USER CODE END 3 */
}

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


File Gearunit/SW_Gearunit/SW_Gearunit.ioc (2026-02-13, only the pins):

Mcu.UserName=STM32F103C8Tx
PA0-WKUP.Signal=ADCx_IN0
PA1.Signal=ADCx_IN1
PA11.Signal=CAN_RX
PA12.Signal=CAN_TX
PA13.Signal=SYS_JTMS-SWDIO
PA14.Signal=SYS_JTCK-SWCLK
PC13-TAMPER-RTC.Signal=GPIO_Output
PC14-OSC32_IN.Signal=RCC_OSC32_IN
PC15-OSC32_OUT.Signal=RCC_OSC32_OUT
PD0-OSC_IN.Signal=RCC_OSC_IN
PD1-OSC_OUT.Signal=RCC_OSC_OUT

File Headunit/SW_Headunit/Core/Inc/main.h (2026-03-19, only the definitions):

#define SPI1_RES_Pin GPIO_PIN_3
#define SPI1_RES_GPIO_Port GPIOA
#define SPI1_CS_Pin GPIO_PIN_4
#define SPI1_CS_GPIO_Port GPIOA
#define SPI_DC_Pin GPIO_PIN_6
#define SPI_DC_GPIO_Port GPIOA

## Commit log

2026-01-25 LVGL use attempt - too large to fit
    [main.c]
2026-01-28 Framebuffer 40*80 at 4bit depth added. Pallet test
2026-01-29 Fixed garbage on startup, tested character output concept
    [ST7735.c, ST7735.h, main.c]
2026-02-01 Started case 3D model
    [Headunit.FCStd, LH096NT-IF09W-Body.step, LH096NT-IF09W.FCStd]
2026-02-02 KiCAD project created
    [HW_Headunit.kicad_pcb, HW_Headunit.kicad_sch, HW_Headunit.step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]
2026-02-02 Fixed issue with putchar() occasional artifacts
    [SW_Headunit.ioc, main.c]
2026-02-03 Headunit case model general vision created
    [HW_Headunit.step, Headunit.FCStd]
2026-02-03 PCB shape improved
    [HW_Headunit.kicad_pcb, HW_Headunit.step, Headunit.FCStd]
2026-02-06 Added Canopen node submodule and added timer for timebase
2026-02-07 Derived Gearunit from Headunit
2026-02-12 Configured transmit PDO for the Gearunit
2026-02-12 Stable PDO transmission, but does not work on CH32F because the second ADC is missing
    [main.c]
2026-02-13 Adapted Gearunit firmware for WCH CH32F103C8
2026-03-15 Basic RPDO implemented for Headunit, display corruption fixed
    [ST7735.c, main.c]
2026-03-16 Started adding gear learn logic
2026-03-17 Started implementing pallete and partial redraw feature, discovered a color corruption bug
    [ST7735.c, ST7735.h, main.c]
2026-03-20 Fixes in shifter gear detection algorithm
    [main.c]
2026-03-23 Exported fabrication files
    [HS096T01H13-Shape2DView.dxf, HS096T01H13.FCStd, HS096T01H13.step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]
2026-03-27 Gearunit update
    [HW_Gearunit.kicad_pcb, HW_Gearunit.kicad_sch, MCU.kicad_sch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]
2026-03-30 Gearunit updates, Readme updated
    [HW_Gearunit.kicad_pcb, HW_Gearunit.kicad_sch, HW_Headunit.kicad_pcb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]
2026-03-30 Renders added, readme updated
    [Headunit.FCStd, Headunit.blend]

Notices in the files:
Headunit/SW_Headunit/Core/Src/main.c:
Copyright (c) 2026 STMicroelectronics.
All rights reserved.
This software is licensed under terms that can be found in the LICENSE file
